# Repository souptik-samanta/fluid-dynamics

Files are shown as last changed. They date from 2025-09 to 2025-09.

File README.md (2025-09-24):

---
name: "Souptik Samanta"
slack_handle: "@Souptik Samanta"
github_handle: "@souptik-samanta"
tutorial: #no
wokwi: https://wokwi.com/projects/429317036413027329
---

# FLuid Dynamics

Wokwi link: https://wokwi.com/projects/429317036413027329

Led matrix pcb with rp2040 embeded into pcb to simulate fuild behavours based on inbuilt imu 

(pls include rough pricing of any extra components you're using 

| QTY  | PART | Approx Price | LCSC |
|-----:|:---|---:|:---|
| 1 | IS31FL3741A-QFLS4-TR - 900Hz~29kHz 2.7V~5.5V QFN-60-EP(7x7) LED Drivers ICs ROHS | $2.89 | C2940604 |
| 5 | XDBS-CR2032-5 - Through Hole Blade Type Power Connector Assemblies ROHS | $0.30 | C48687404 |
| 2 | W25Q128JVSIQ - 128Mbit 2.7V~3.6V 133MHz SPI SOIC-8-208mil Memory (ICs) ROHS | $2.17 | C97521 |
| 5 | AMS1117-3.3 - 72dB@(120Hz) Positive SOT-223 Voltage Regulators - Linear, Low Drop Out (LDO) Regulators ROHS | $0.84 | C6186 |
| 1 | RP2040 - 133MHz LQFN-56(7x7) Microcontrollers ROHS | $1.14 | C2040 |
| 10 | SRV05-4 - 5A 75W 12.5V 6V Unidirectional SOT-23-6L TVS Diodes ROHS | $0.84 | C7420376 |
| 100  | FRC1206F2002TS - 250mW 20kΩ 200V ±100ppm/℃ Thick Film Resistor ±1% 1206 Chip Resistor - Surface Mount ROHS | $0.29 | C2933636 |
| 100  | 0402WGF274JTCE - 27.4Ω 62.5mW 50V ±100ppm/℃ Thick Film Resistor ±1% 0402 Chip Resistor - Surface Mount ROHS | $0.06 | C31439 |
| 100  | 0402WGF5101TCE - 5.1kΩ 62.5mW 50V ±100ppm/℃ Thick Film Resistor ±1% 0402 Chip Resistor - Surface Mount ROHS | $0.05 | C25905 |
| 100  | 0402WGF1001TCE - 1kΩ 62.5mW 50V ±100ppm/℃ Thick Film Resistor ±1% 0402 Chip Resistor - Surface Mount ROHS | $0.06 | C11702 |

final all toal is 20 - 25$ for parts  more parts on https://docs.google.com/spreadsheets/d/1B7IjNo7W825W_gv3a4BfWUKZrWtPnMB5DJiVofmm6nU/edit?usp=sharing

eh pretty easy 







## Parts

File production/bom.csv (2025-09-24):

Designator | Footprint | Quantity | Value | LCSC Part #
C1, C2 | 0402 | 2 | 15pF
C10, C13, C14, C15, C16, C17, C18, C19, C9 | 0402 | 9 | 100nF
C11, C12, C20 | 0402 | 3 | 1uF
C23, C26 | 0603 | 2 | .1uF
C24 | 0603 | 1 | 2.2nF
C25 | 0603 | 1 | 10nF
C3 | 0402 | 1 | 100n
C30 | 0805 | 1 | 10uF
C31 | 0805 | 1 | 1uF
C4, C6 | 0603 | 2 | 10uF
C5, C7, C8 | 0603 | 3 | 22uF
D1, D2 | 0402 | 2 | LED
D3, D4, D_L_1_1, D_L_1_2, D_L_1_3, D_L_1_4, D_L_1_5, D_L_1_6, D_L_1_7, D_L_1_8, D_L_2_1, D_L_2_2, D_L_2_3, D_L_2_4, D_L_2_5, D_L_2_6, D_L_2_7, D_L_2_8, D_L_3_1, D_L_3_2, D_L_3_3, D_L_3_4, D_L_3_5, D_L_3_6, D_L_3_7, D_L_3_8, D_L_4_1, D_L_4_2, D_L_4_3, D_L_4_4, D_L_4_5, D_L_4_6, D_L_4_7, D_L_4_8, D_L_5_1, D_L_5_2, D_L_5_3, D_L_5_4, D_L_5_5, D_L_5_6, D_L_5_7, D_L_5_8, D_L_6_1, D_L_6_2, D_L_6_3, D_L_6_4, D_L_6_5, D_L_6_6, D_L_6_7, D_L_6_8 | 0603 | 50 | LED
FB1 | 0805 | 1 | 120ohm.100Mhz
J2 | USB_C_Receptacle_HCTL_HC-TYPE-C-16P-01A | 1 | USB_C_Receptacle_USB2.0_14P
J4 | PinHeader_1x03_P1.00mm_Vertical_SMD_Pin1Left | 1 | Conn_01x03_Pin
J5 | PinHeader_1x04_P1.00mm_Vertical | 1 | Conn_01x04_Pin
R1, R14, R15, R2 | 0402 | 4 | 220
R10, R3 | 0402 | 2 | 1k
R12, R13 | 0402 | 2 | 5.1K
R16, R17 | 0402 | 2 | 27.4
R20 | 1206 | 1 | 20K
SW1 | SW_Push_SPST_NO_Alps_SKRK | 1 | GP0 | C318884
SW2 | SW_Push_SPST_NO_Alps_SKRK | 1 | BOOT_SEL | C318884
U1 | SOT-23-6 | 1 | SRV05-4
U2 | SOIC-8_5.3x5.3mm_P1.27mm | 1 | W25Q128JVS
U3 | SOT-223-3_TabPin2 | 1 | AMS1117-3.3
U4 | QFN-56-1EP_7x7mm_P0.4mm_EP3.2x3.2mm | 1 | RP2040
U5 | InvenSense_QFN-24_4x4mm_P0.5mm | 1 | MPU-6050
U6 | QFN-28-1EP_4x4mm_P0.4mm_EP2.4x2.4mm_ThermalVias | 1 | IS31FL3731-QF
Y1 | Crystal_SMD_Abracon_ABM8G-4Pin_3.2x2.5mm | 1 | Crystal_GND24

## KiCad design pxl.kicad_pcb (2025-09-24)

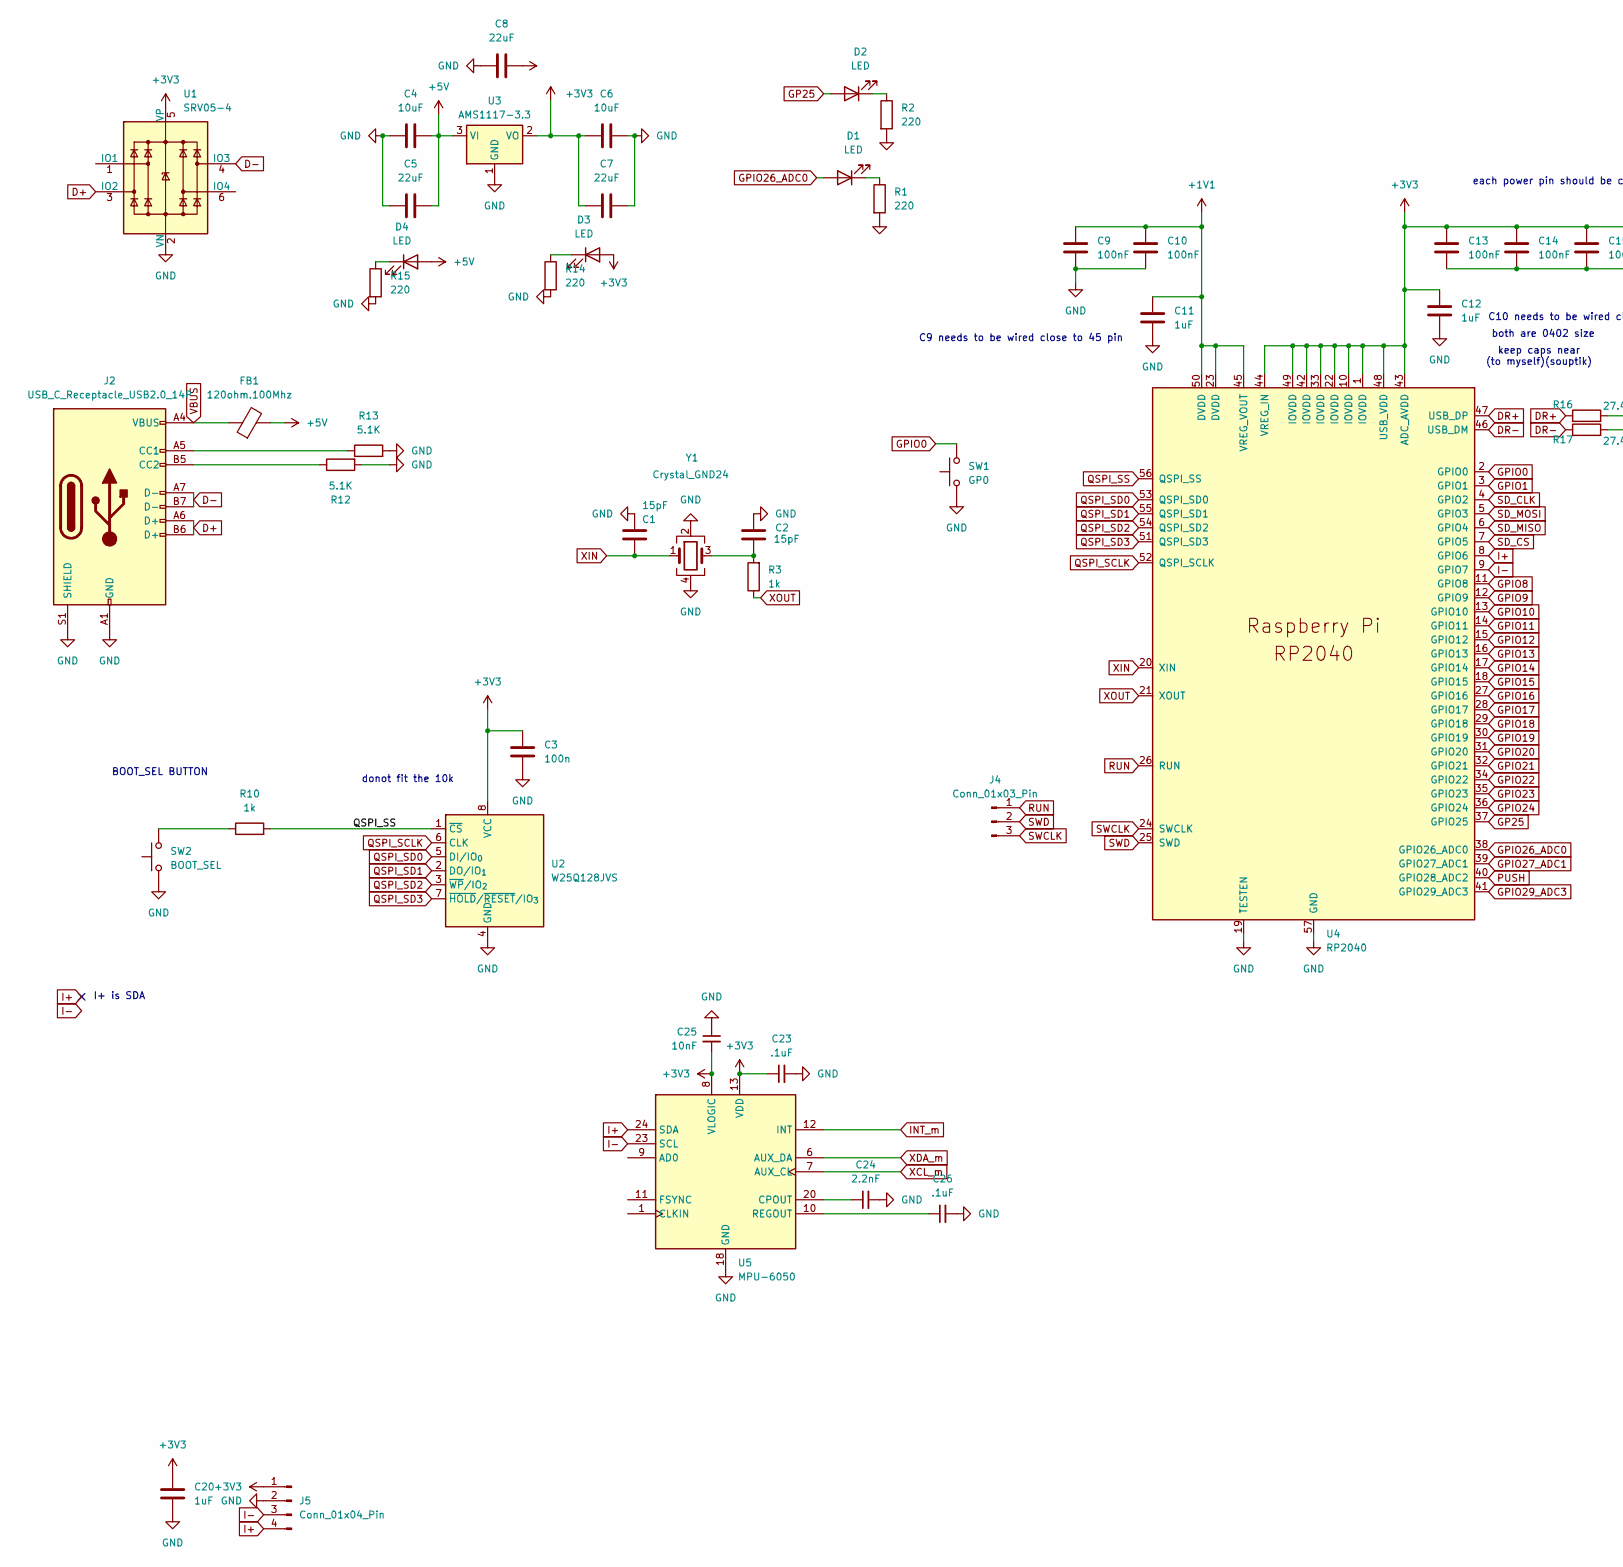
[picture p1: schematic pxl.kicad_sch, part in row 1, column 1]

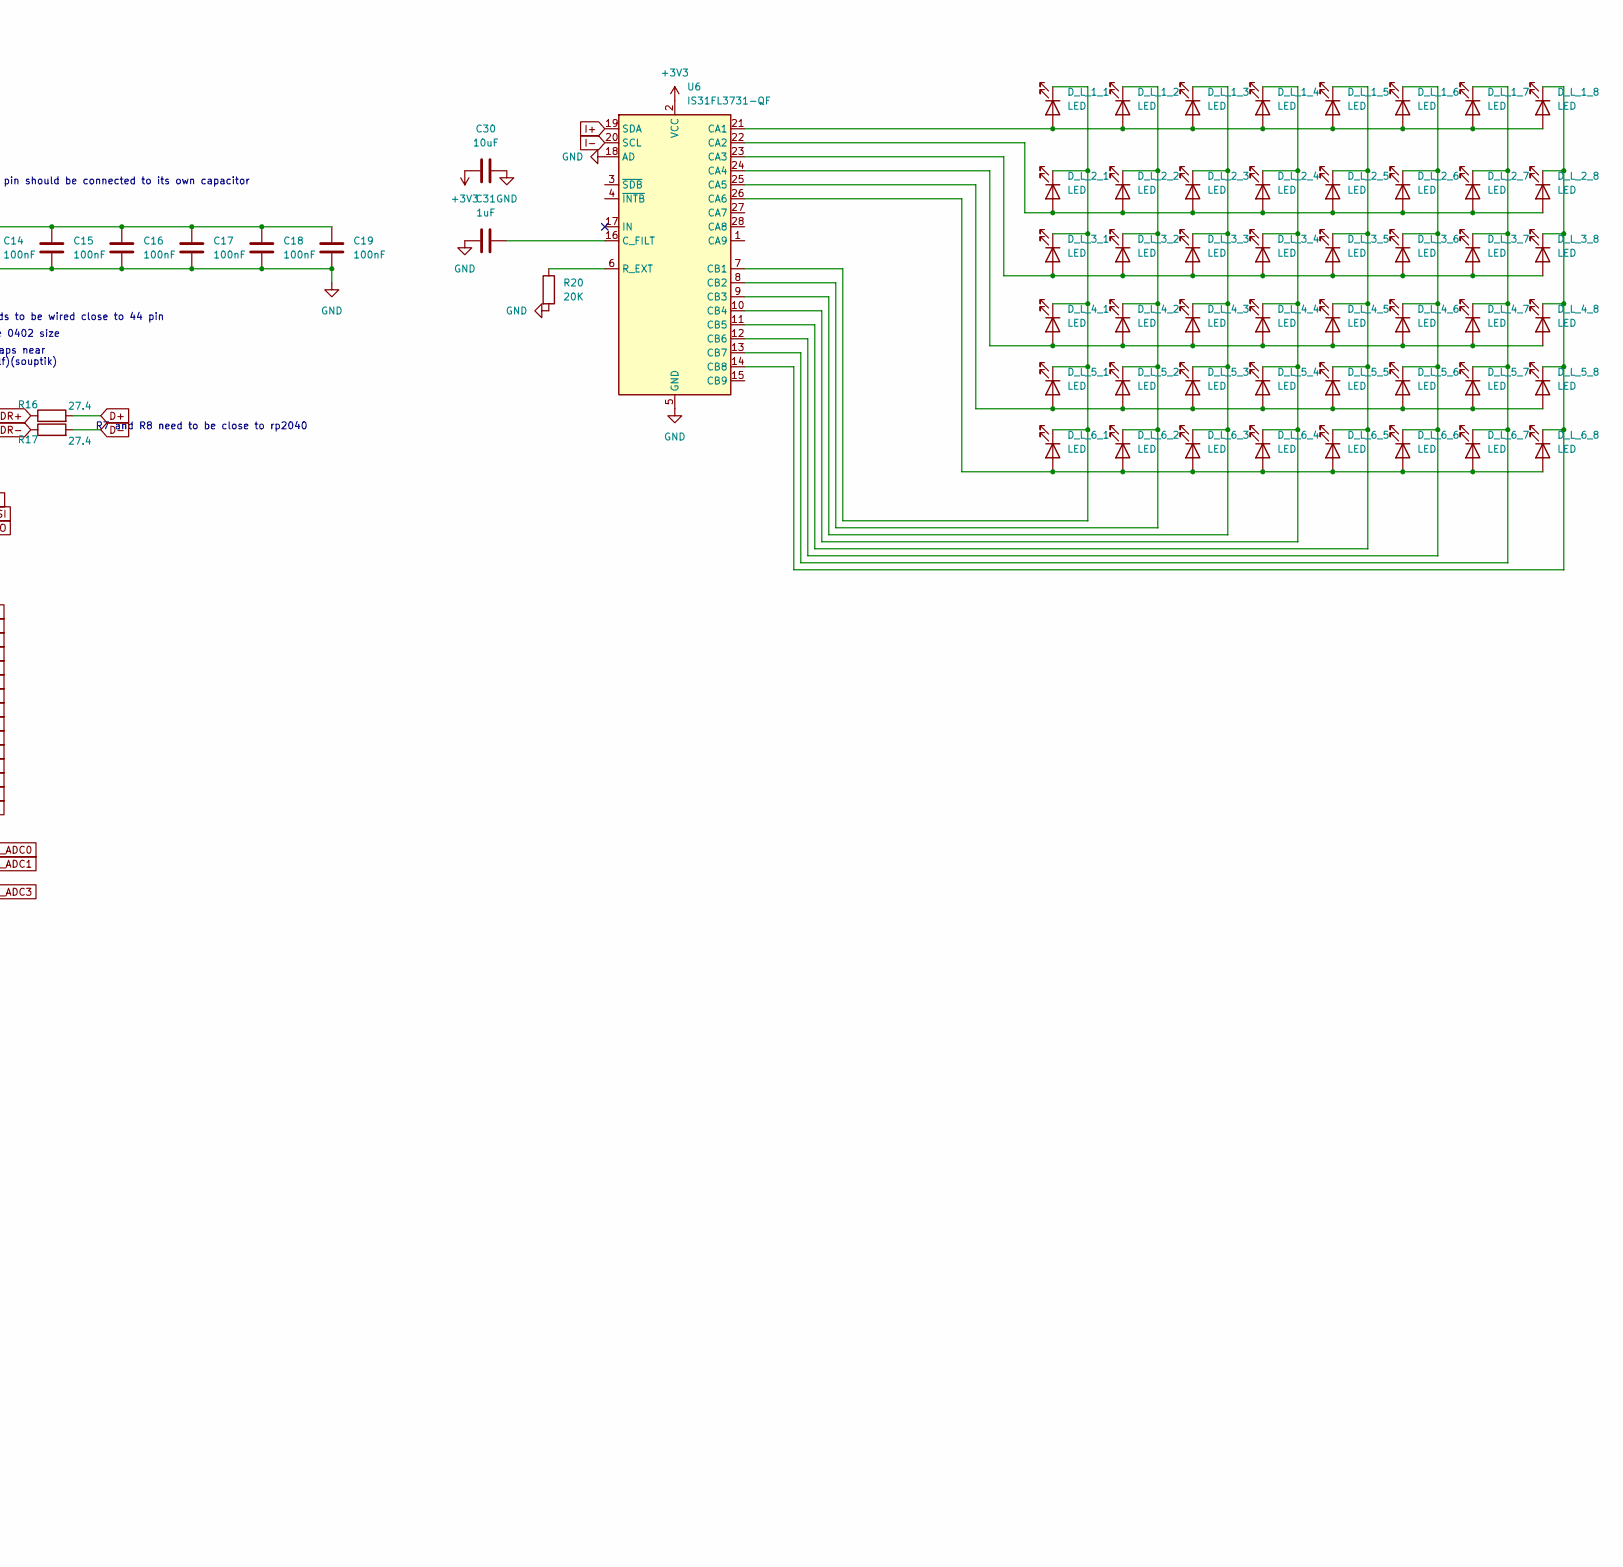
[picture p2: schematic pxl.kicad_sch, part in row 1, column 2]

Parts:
C1, C2: 15pF; C_0402_1005Metric
C3: 100n; C_0402_1005Metric
C4, C6: 10uF; C_0603_1608Metric
C5, C7, C8: 22uF; C_0603_1608Metric
C9, C10, C13, C14, C15, C16, C17, C18, C19: 100nF; C_0402_1005Metric
C11, C12, C20: 1uF; C_0402_1005Metric
C23, C26: .1uF; C_0603_1608Metric_Pad1.08x0.95mm_HandSolder
C24: 2.2nF; C_0603_1608Metric_Pad1.08x0.95mm_HandSolder
C25: 10nF; C_0603_1608Metric_Pad1.08x0.95mm_HandSolder
C30: 10uF; C_0805_2012Metric
C31: 1uF; C_0805_2012Metric
D1, D2: LED; LED_0402_1005Metric
D3, D4: LED; LED_0603_1608Metric
D_L_1_1, D_L_1_2, D_L_1_3, D_L_1_4, D_L_1_5, D_L_1_6, D_L_1_7, D_L_1_8, D_L_2_1, D_L_2_2, D_L_2_3, D_L_2_4, D_L_2_5, D_L_2_6, D_L_2_7, D_L_2_8, D_L_3_1, D_L_3_2, D_L_3_3, D_L_3_4, D_L_3_5, D_L_3_6, D_L_3_7, D_L_3_8, D_L_4_1, D_L_4_2, D_L_4_3, D_L_4_4, D_L_4_5, D_L_4_6, D_L_4_7, D_L_4_8, D_L_5_1, D_L_5_2, D_L_5_3, D_L_5_4, D_L_5_5, D_L_5_6, D_L_5_7, D_L_5_8, D_L_6_1, D_L_6_2, D_L_6_3, D_L_6_4, D_L_6_5, D_L_6_6, D_L_6_7, D_L_6_8: LED; LED_0603_1608Metric
FB1: 120ohm.100Mhz; L_0805_2012Metric
J2: USB_C_Receptacle_USB2.0_14P; USB_C_Receptacle_HCTL_HC-TYPE-C-16P-01A
J4: Conn_01x03_Pin; PinHeader_1x03_P1.00mm_Vertical_SMD_Pin1Left
J5: Conn_01x04_Pin; PinHeader_1x04_P1.00mm_Vertical
R1, R2, R14, R15: 220; R_0402_1005Metric
R3, R10: 1k; R_0402_1005Metric
R12, R13: 5.1K; C_0402_1005Metric
R16, R17: 27.4; R_0402_1005Metric
R20: 20K; R_1206_3216Metric_Pad1.30x1.75mm_HandSolder
SW1: GP0; SW_Push_SPST_NO_Alps_SKRK; LCSC C318884
SW2: BOOT_SEL; SW_Push_SPST_NO_Alps_SKRK; LCSC C318884
U1: SRV05-4; SOT-23-6
U2: W25Q128JVS; SOIC-8_5.3x5.3mm_P1.27mm
U3: AMS1117-3.3; SOT-223-3_TabPin2
U4: RP2040; QFN-56-1EP_7x7mm_P0.4mm_EP3.2x3.2mm
U5: MPU-6050; InvenSense_QFN-24_4x4mm_P0.5mm
U6: IS31FL3731-QF; QFN-28-1EP_4x4mm_P0.4mm_EP2.4x2.4mm_ThermalVias
Y1: Crystal_GND24; Crystal_SMD_Abracon_ABM8G-4Pin_3.2x2.5mm

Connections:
+1V1: C9.1, C10.1, C11.1, U4.23 (DVDD), U4.45 (VREG_VOUT), U4.50 (DVDD)
+3V3: C3.1, C6.2, C7.2, C12.1, C13.1, C14.1, C15.1, C16.1, C17.1, C18.1, C19.1, C20.1, C23.1, C25.2, C30.2, D3.2 (A), J5.1, U1.5 (VP), U2.8 (VCC), U3.2 (VO), U4.1 (IOVDD), U4.10 (IOVDD), U4.22 (IOVDD), U4.33 (IOVDD), U4.42 (IOVDD), U4.43 (ADC_AVDD), U4.44 (VREG_IN), U4.48 (USB_VDD), U4.49 (IOVDD), U5.8 (VLOGIC), U5.13 (VDD), U6.2 (VCC)
+5V: C4.1, C5.1, C8.1, D4.2 (A), FB1.2, U3.3 (VI)
D+: J2.A6 (D+), J2.B6 (D+), R16.2, U1.3 (IO2)
D-: J2.A7 (D-), J2.B7 (D-), R17.2, U1.4 (IO3)
DR+: R16.1, U4.47 (USB_DP)
DR-: R17.1, U4.46 (USB_DM)
GND: C1.2, C2.2, C3.2, C4.2, C5.2, C6.1, C7.1, C8.2, C9.2, C10.2, C11.2, C12.2, C13.2, C14.2, C15.2, C16.2, C17.2, C18.2, C19.2, C20.2, C23.2, C24.2, C25.1, C26.2, C30.1, C31.2, J2.A1 (GND), J2.A12 (GND), J2.B1 (GND), J2.B12 (GND), J2.S1 (SHIELD), J5.2, R1.2, R2.2, R12.2, R13.2, R14.2, R15.2, R20.2, SW1.1, SW2.1, U1.2 (VN), U2.4 (GND), U3.1 (GND), U4.19 (TESTEN), U4.57 (GND), U5.18 (GND), U6.5 (GND), U6.18 (AD), U6.29 (GND), Y1.2, Y1.4
GP25: D2.2 (A), U4.37 (GPIO25)
GPIO0: SW1.2, U4.2 (GPIO0)
GPIO1: U4.3 (GPIO1)
GPIO8: U4.11 (GPIO8)
GPIO9: U4.12 (GPIO9)
GPIO10: U4.13 (GPIO10)
GPIO11: U4.14 (GPIO11)
GPIO12: U4.15 (GPIO12)
GPIO13: U4.16 (GPIO13)
GPIO14: U4.17 (GPIO14)
GPIO15: U4.18 (GPIO15)
GPIO16: U4.27 (GPIO16)
GPIO17: U4.28 (GPIO17)
GPIO18: U4.29 (GPIO18)
GPIO19: U4.30 (GPIO19)
GPIO20: U4.31 (GPIO20)
GPIO21: U4.32 (GPIO21)
GPIO22: U4.34 (GPIO22)
GPIO23: U4.35 (GPIO23)
GPIO24: U4.36 (GPIO24)
GPIO26_ADC0: D1.2 (A), U4.38 (GPIO26_ADC0)
GPIO27_ADC1: U4.39 (GPIO27_ADC1)
GPIO29_ADC3: U4.41 (GPIO29_ADC3)
I+: J5.4, U4.8 (GPIO6), U5.24 (SDA), U6.19 (SDA)
I-: J5.3, U4.9 (GPIO7), U5.23 (SCL), U6.20 (SCL)
INT_m: U5.12 (INT)
unnamed: C2.1, R3.2, Y1.3
unnamed: D1.1 (K), R1.1
unnamed: D2.1 (K), R2.1
unnamed: D3.1 (K), R14.1
unnamed: D4.1 (K), R15.1
unnamed: D_L_1_1.2 (A), D_L_1_2.2 (A), D_L_1_3.2 (A), D_L_1_4.2 (A), D_L_1_5.2 (A), D_L_1_6.2 (A), D_L_1_7.2 (A), D_L_1_8.2 (A), U6.21 (CA1)
unnamed: D_L_1_1.1 (K), D_L_2_1.1 (K), D_L_3_1.1 (K), D_L_4_1.1 (K), D_L_5_1.1 (K), D_L_6_1.1 (K), U6.7 (CB1)
unnamed: D_L_1_2.1 (K), D_L_2_2.1 (K), D_L_3_2.1 (K), D_L_4_2.1 (K), D_L_5_2.1 (K), D_L_6_2.1 (K), U6.8 (CB2)
unnamed: D_L_1_3.1 (K), D_L_2_3.1 (K), D_L_3_3.1 (K), D_L_4_3.1 (K), D_L_5_3.1 (K), D_L_6_3.1 (K), U6.9 (CB3)
unnamed: D_L_1_4.1 (K), D_L_2_4.1 (K), D_L_3_4.1 (K), D_L_4_4.1 (K), D_L_5_4.1 (K), D_L_6_4.1 (K), U6.10 (CB4)
unnamed: D_L_1_5.1 (K), D_L_2_5.1 (K), D_L_3_5.1 (K), D_L_4_5.1 (K), D_L_5_5.1 (K), D_L_6_5.1 (K), U6.11 (CB5)
unnamed: D_L_1_6.1 (K), D_L_2_6.1 (K), D_L_3_6.1 (K), D_L_4_6.1 (K), D_L_5_6.1 (K), D_L_6_6.1 (K), U6.12 (CB6)
unnamed: D_L_1_7.1 (K), D_L_2_7.1 (K), D_L_3_7.1 (K), D_L_4_7.1 (K), D_L_5_7.1 (K), D_L_6_7.1 (K), U6.13 (CB7)
unnamed: D_L_1_8.1 (K), D_L_2_8.1 (K), D_L_3_8.1 (K), D_L_4_8.1 (K), D_L_5_8.1 (K), D_L_6_8.1 (K), U6.14 (CB8)
unnamed: D_L_2_1.2 (A), D_L_2_2.2 (A), D_L_2_3.2 (A), D_L_2_4.2 (A), D_L_2_5.2 (A), D_L_2_6.2 (A), D_L_2_7.2 (A), D_L_2_8.2 (A), U6.22 (CA2)
unnamed: D_L_3_1.2 (A), D_L_3_2.2 (A), D_L_3_3.2 (A), D_L_3_4.2 (A), D_L_3_5.2 (A), D_L_3_6.2 (A), D_L_3_7.2 (A), D_L_3_8.2 (A), U6.23 (CA3)
unnamed: D_L_4_1.2 (A), D_L_4_2.2 (A), D_L_4_3.2 (A), D_L_4_4.2 (A), D_L_4_5.2 (A), D_L_4_6.2 (A), D_L_4_7.2 (A), D_L_4_8.2 (A), U6.24 (CA4)
unnamed: D_L_5_1.2 (A), D_L_5_2.2 (A), D_L_5_3.2 (A), D_L_5_4.2 (A), D_L_5_5.2 (A), D_L_5_6.2 (A), D_L_5_7.2 (A), D_L_5_8.2 (A), U6.25 (CA5)
unnamed: D_L_6_1.2 (A), D_L_6_2.2 (A), D_L_6_3.2 (A), D_L_6_4.2 (A), D_L_6_5.2 (A), D_L_6_6.2 (A), D_L_6_7.2 (A), D_L_6_8.2 (A), U6.26 (CA6)
unnamed: J2.A5 (CC1), R13.1
unnamed: J2.B5 (CC2), R12.1
unnamed: R10.1, SW2.2
unnamed: C24.1, U5.20 (CPOUT)
unnamed: C26.1, U5.10 (REGOUT)
unnamed: C31.1, U6.16 (C_FILT)
unnamed: R20.1, U6.6 (R_EXT)
PUSH: U4.40 (GPIO28_ADC2)
QSPI_SCLK: U2.6 (CLK), U4.52 (QSPI_SCLK)
QSPI_SD0: U2.5 (DI/IO_{0}), U4.53 (QSPI_SD0)
QSPI_SD1: U2.2 (DO/IO_{1}), U4.55 (QSPI_SD1)
QSPI_SD2: U2.3 (~WP/IO_{2}), U4.54 (QSPI_SD2)
QSPI_SD3: U2.7 (~HOLD/~RESET/IO_{3}), U4.51 (QSPI_SD3)
QSPI_SS: R10.2, U2.1 (~CS), U4.56 (QSPI_SS)
RUN: J4.1, U4.26 (RUN)
SD_CLK: U4.4 (GPIO2)
SD_CS: U4.7 (GPIO5)
SD_MISO: U4.6 (GPIO4)
SD_MOSI: U4.5 (GPIO3)
SWCLK: J4.3, U4.24 (SWCLK)
SWD: J4.2, U4.25 (SWD)
VBUS: FB1.1, J2.A4 (VBUS), J2.A9 (VBUS), J2.B4 (VBUS), J2.B9 (VBUS)
XCL_m: U5.7 (AUX_CL)
XDA_m: U5.6 (AUX_DA)
XIN: C1.1, U4.20 (XIN), Y1.1
XOUT: R3.1, U4.21 (XOUT)

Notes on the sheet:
each power pin should be connected to its own capacitor
keep caps near (to myself)(souptik)
C9 needs to be wired close to 45 pin
donot fit the 10k
both are 0402 size
R7 and R8 need to be close to rp2040
I+ is SDA
BOOT_SEL BUTTON
C10 needs to be wired close to 44 pin

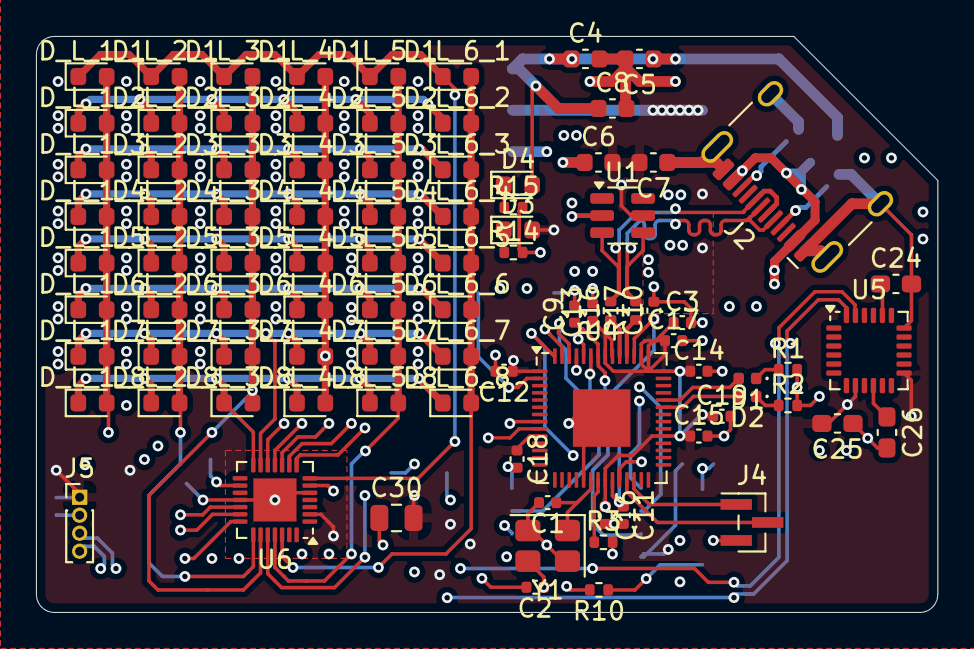
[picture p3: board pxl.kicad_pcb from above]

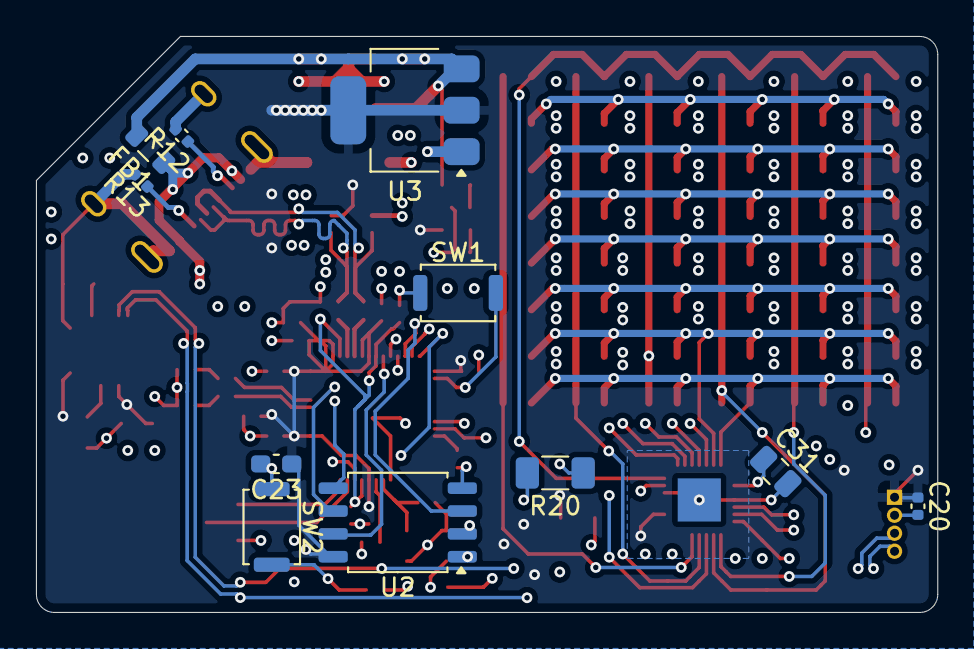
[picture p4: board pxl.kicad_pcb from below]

Board: 4 copper layers, 50.1 x 32.0 mm, 102 parts (11 on the bottom side), 51 nets.
